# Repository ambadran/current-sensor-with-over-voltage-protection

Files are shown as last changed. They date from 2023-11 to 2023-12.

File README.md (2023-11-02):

Current sensor circuit with over voltage protection.

The Voltage supported is 12<=V<=18 as this is the working range of the TL092 OpAmps used in this project.

The shunt is a 1ohm 10 watt resistor, so use current*voltage under 10watt

The overvoltage protection circuit makes sure the output is NEVER above the Vref set by 
the TL431 IC in the circuit, a potentiometer is connected for ease of setting it to 
whatever your microcontroller max Vdd (e.g 3.3v or 5v).

A single layer PCB is also designed if needed.

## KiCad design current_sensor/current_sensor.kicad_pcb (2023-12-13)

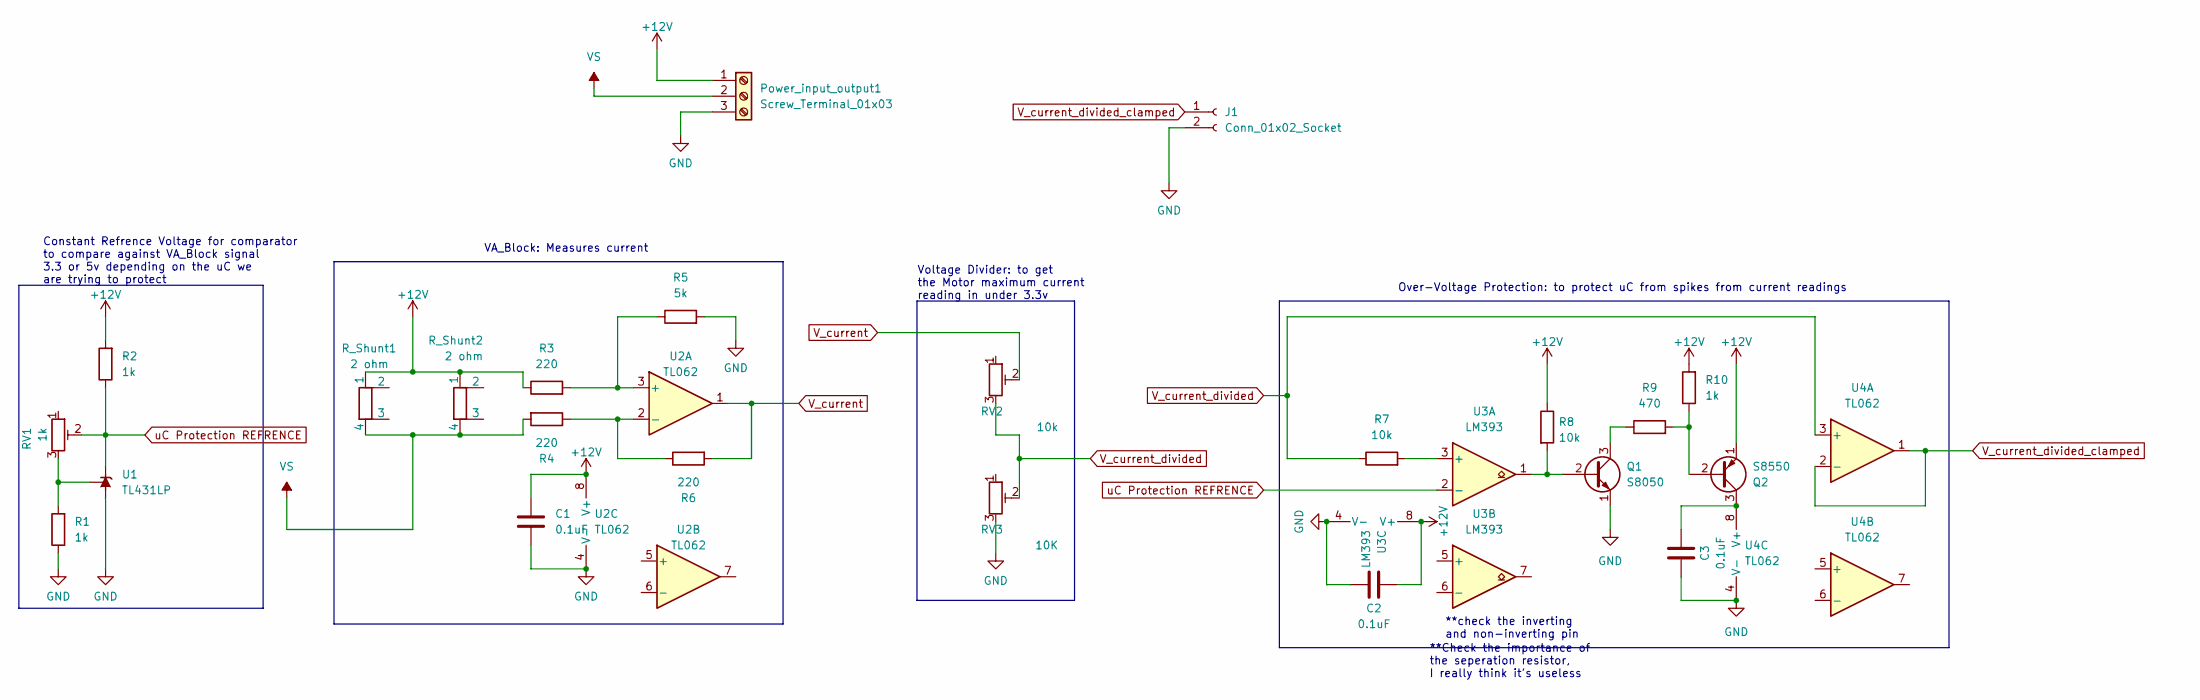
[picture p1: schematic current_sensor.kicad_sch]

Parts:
C1, C2, C3: 0.1uF; C_Disc_D5.0mm_W2.5mm_P5.00mm
J1: Conn_01x02_Socket; PinSocket_1x02_P2.54mm_Vertical
Power_input_output1: Screw_Terminal_01x03; TerminalBlock_bornier-3_P5.08mm
Q1: S8050; TO-92_Inline
Q2: S8550; TO-92_Inline
R1, R2, R10: 1k; R_Axial_DIN0207_L6.3mm_D2.5mm_P7.62mm_Horizontal
R3, R4, R6: 220; R_Axial_DIN0207_L6.3mm_D2.5mm_P7.62mm_Horizontal
R5: 5k; R_Axial_DIN0207_L6.3mm_D2.5mm_P7.62mm_Horizontal
R7, R8: 10k; R_Axial_DIN0207_L6.3mm_D2.5mm_P7.62mm_Horizontal
R9: 470; R_Axial_DIN0207_L6.3mm_D2.5mm_P7.62mm_Horizontal
RV1: 1k; PinSocket_1x03_P2.54mm_Vertical
RV2: 10k; PinSocket_1x03_P2.54mm_Vertical
RV3: 10K; PinSocket_1x03_P2.54mm_Vertical
R_Shunt1, R_Shunt2: 2 ohm; R_Axial_Shunt_L22.2mm_W9.5mm_PS14.30mm_P25.40mm
U1: TL431LP; TO-92_Inline
U2, U4: TL062; DIP-8_W7.62mm_Socket_LongPads
U3: LM393; DIP-8_W7.62mm_Socket_LongPads

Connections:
+12V: C1.1, C2.2, Power_input_output1.1, Q2.1 (E), R2.2, R3.1, R8.1, R10.2, R_Shunt1.1, R_Shunt2.1, U2.8 (V+), U3.8 (V+)
GND: C1.2, C2.1, C3.1, J1.2, Power_input_output1.3, Q1.1 (E), R1.1, R5.2, RV3.3, U1.2 (A), U2.4 (V-), U3.4 (V-), U4.4 (V-)
unnamed: Q1.2 (B), R8.2, U3.1
unnamed: Q1.3 (C), R9.1
unnamed: Q2.2 (B), R9.2, R10.1
unnamed: C3.2, Q2.3 (C), U4.8 (V+)
unnamed: R1.2, RV1.3, U1.1 (REF)
unnamed: R3.2, R5.1, U2.3 (+)
unnamed: R4.1, R6.1, U2.2 (-)
unnamed: R7.2, U3.3 (+)
VS: Power_input_output1.2, R4.2, R_Shunt1.4, R_Shunt2.4
V_current: R6.2, RV2.2, U2.1
V_current_divided: R7.1, RV2.3, RV3.2, U4.3 (+)
V_current_divided_clamped: J1.1, U4.1, U4.2 (-)
uC Protection REFRENCE: R2.1, RV1.2, U1.3 (K), U3.2 (-)

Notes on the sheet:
**check the inverting and non-inverting pin
Over-Voltage Protection: to protect uC from spikes from current readings
VA_Block: Measures current
Voltage Divider: to get the Motor maximum current reading in under 3.3v
Constant Refrence Voltage for comparator to compare against VA_Block signal 3.3 or 5v depending on the uC we are trying to protect
**Check the importance of the seperation resistor, I really think it's useless

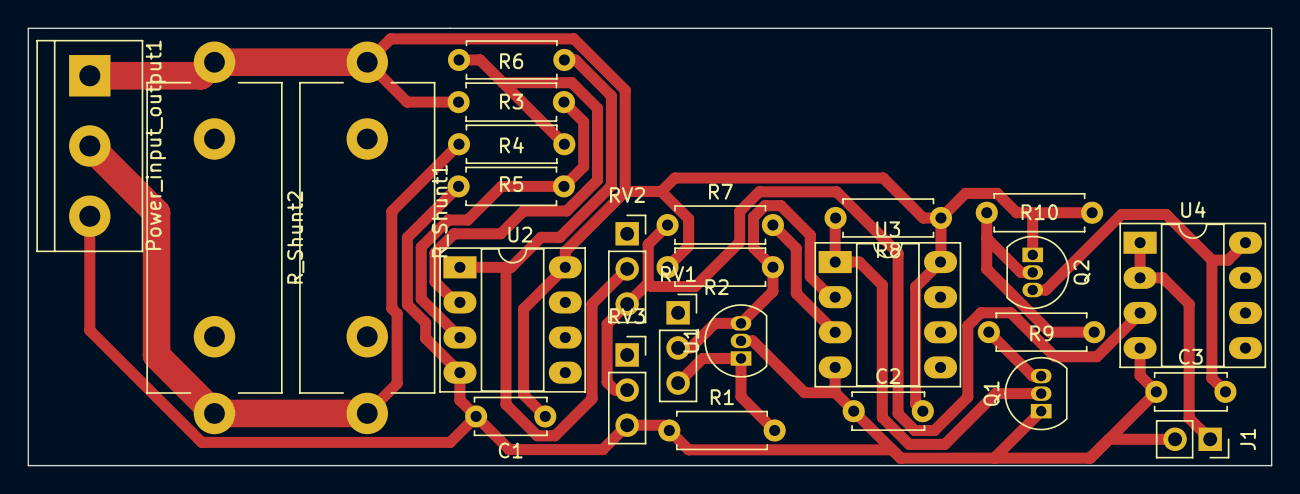
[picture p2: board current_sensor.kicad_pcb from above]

Board: 2 copper layers, 89.9 x 31.6 mm, 26 parts (0 on the bottom side), 15 nets.

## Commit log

2023-11-02 Designed and tested schematic on breadboard
    [current_sensor.kicad_pcb, current_sensor.kicad_sch]
2023-11-02 Finished PCB Design
    [current_sensor.kicad_pcb, current_sensor.kicad_sch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]
2023-11-02 minor modifications to help PCB CAM
    [current_sensor.kicad_pcb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]
2023-12-13 Final Version Ready
    [current_sensor.kicad_pcb, current_sensor.kicad_sch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]
